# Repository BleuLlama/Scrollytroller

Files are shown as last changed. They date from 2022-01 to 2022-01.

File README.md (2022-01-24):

# Scrollytroller
Scrollytroller is a crank-based USB controller, initially inteneded for use with Playdate's Pulp web-based game development tool.

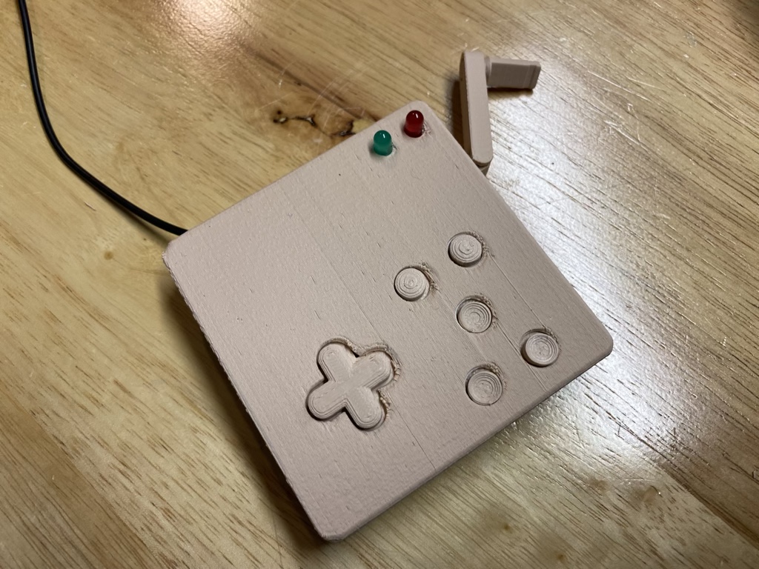
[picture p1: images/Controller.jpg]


This is a USB controller that lets you try out your Playdate Pulp games with a more accurate 
user interface, compared with using your keyboard.

# Function
The controller generates keyboard presses and mouse scroll wheel events so that the 
Pulp web player will interact with it properly.  (I added more buttons and the LEDs because I 
had the space and thought they might be useful.)

The current mouse+keyboard configuration is:

- Crank generates mouse scroll wheel events
- D-Pad generates keyboard arrow key press events
- A and B buttons - generate keyboard 'a' and 's' events
- C button (in the middle) - not used 
- D and E bottom buttons - generate 'cmd'-'s' to save and 'cmd'-'b' to toggle between the player and the editor

In general use, just the green LED will be lit.
You can switch it into "joystick" mode by pushing in the crank button.  The red LED will light up.
While in this config mode, you can turn the crank to reset it, to match the web player.
You can also press the A and B buttons to switch output modes.  The green LED should be off after
you first power up the unit.  This indicates that you're in keyboard+mouse mode.  Press the B button
to switch to Joystick mode.  The green LED will be lit.

The current joystick configuration is:

- D-Pad generates output on axis 0 (x) and axis 1 (y)
 - Range sent is from -1 to +1, with 0 being the "middle"
- A,B,D,E buttons will generate presses on buttons 0,1,2,3 respectively
 - These send 0 when idle, 1, when pressed
- Crank will output on axis 2, and the range of the axis corresponds to one full revolution of the crank.
 - This sends a value from 0..360, and loops around when a full revolution occurs in either direction

Note: The code defines the full revolution based on a couple factors that are specific to the rotary encoder that I'm using.  Mine has 20 detents per full revolution, and each detent sends a cycle of all 4 gray-code encoder phases.

# Arduino Code

The code is written with the Arduino tools, and requires the Encoder library from PJRC, and the
joystick library from Matthew Heironimus. The urls for these libraries can be found in the source
code, and may be able to be installed through the Arduino Library manager.

This project requires an Arduino board with an ATmega 32u4 chip - Leonardo, Pro Micro, or in
my case, I used the "SS Micro" clone board because I like the formfactor.

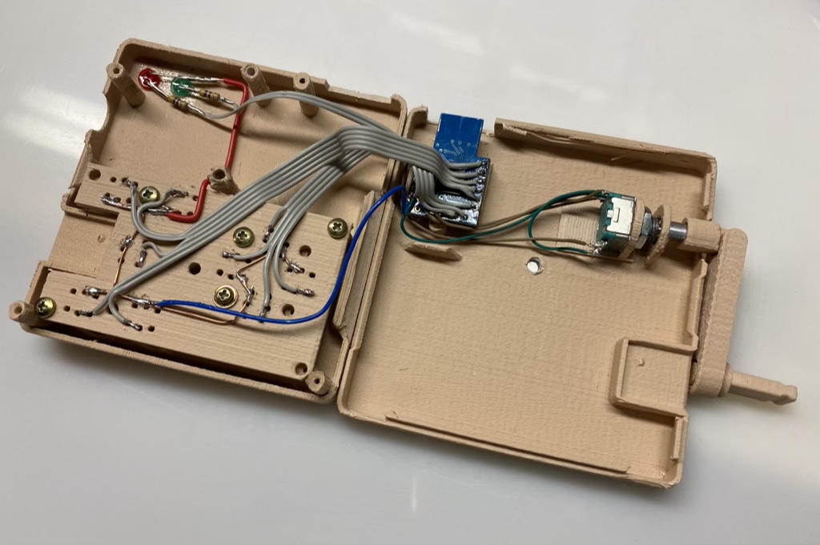
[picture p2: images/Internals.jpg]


The connection details are in the Arduino source code.  But the short of it is that 
all button io is configured using the 32u4's internal pullups, so none are needed
in the external wiring.  All connections go directly to the buttons.  The "other pin" 
on the buttons go to a common ground.  LEDs are wired up in a "source" configuration
where a HIGH from the Arduino will turn the LEDs on.  I used a 510 ohm resistor on each
to keep the current (and brightness) down quite a bit.

# Printable Model

The 3D model started out as the Adafruit "[USB Crank Controller](https://www.thingiverse.com/thing:3685130)" model on Thingiverse.  I widened
it, and created the D-Pad and buttons, as well as mounting standoffs so that it can
be screwed together.  

My version, seen above, started with that model, but I took it in [Tinkercad](https://tinkercad.com), chopped it up, and made a squareish version, with space for a D-Pad and buttons

# Links
- [Playdate](https://play.date)
- [Playdate Pulp](https://play.date/pulp)
- [Scrollytroller on Thingiverse](https://www.thingiverse.com/thing:5215011)
- [Adafruit's USB Crank Controller](https://www.thingiverse.com/thing:3685130)

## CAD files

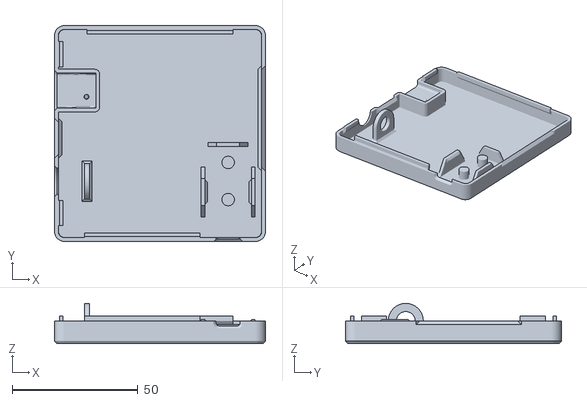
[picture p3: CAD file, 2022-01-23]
Printables/Controller/rotary usb controller - Enclosure Bottom.stl
84.0 x 86.0 x 16.0

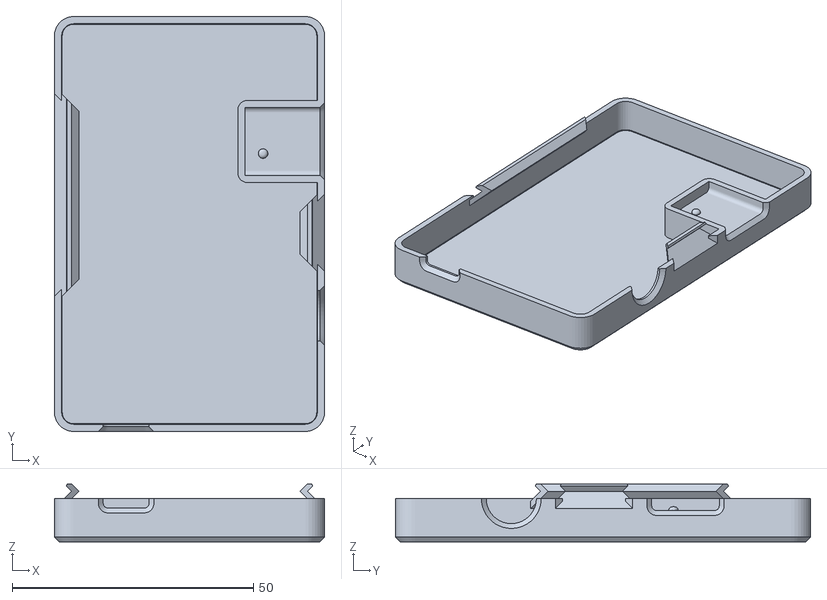
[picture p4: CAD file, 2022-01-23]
Printables/crankbox - original/crankbox-top.stl
56.0 x 86.0 x 12.0

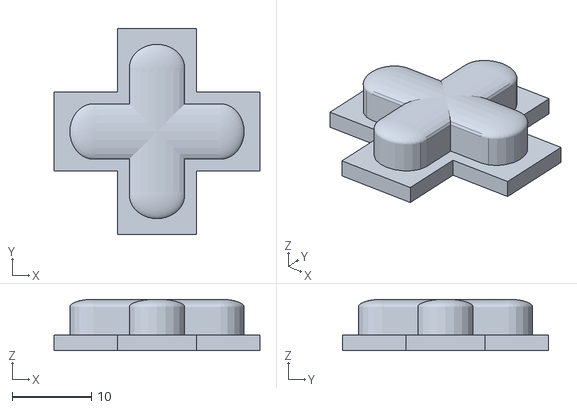
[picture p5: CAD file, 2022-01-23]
Printables/Controller/rotary usb controller - D-Pad.stl
26.0 x 26.0 x 6.50

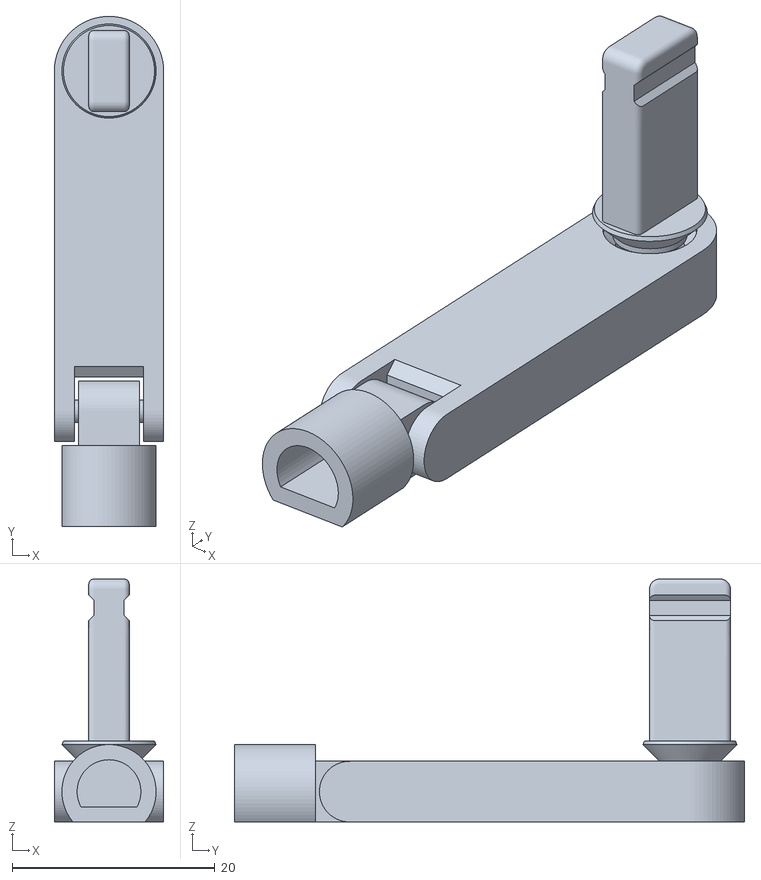
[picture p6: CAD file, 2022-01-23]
Printables/crankbox - original/hinged-crank-dual.stl
10.8 x 50.4 x 24.0

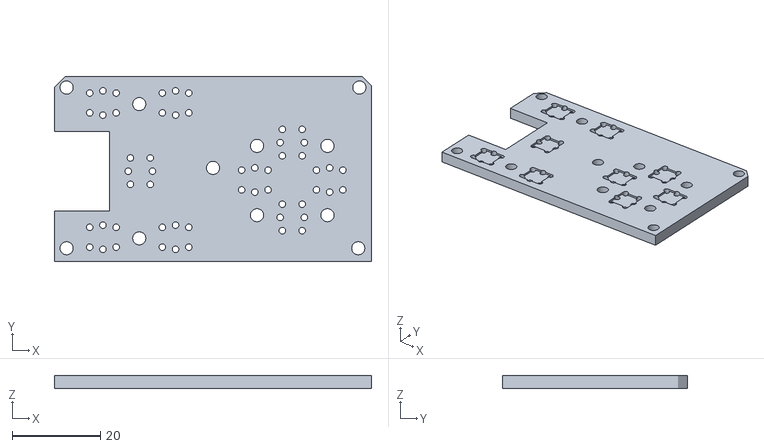
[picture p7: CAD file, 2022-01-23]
Printables/Controller/rotary usb controller - Board-6mm switches.stl
72.0 x 42.0 x 3.00

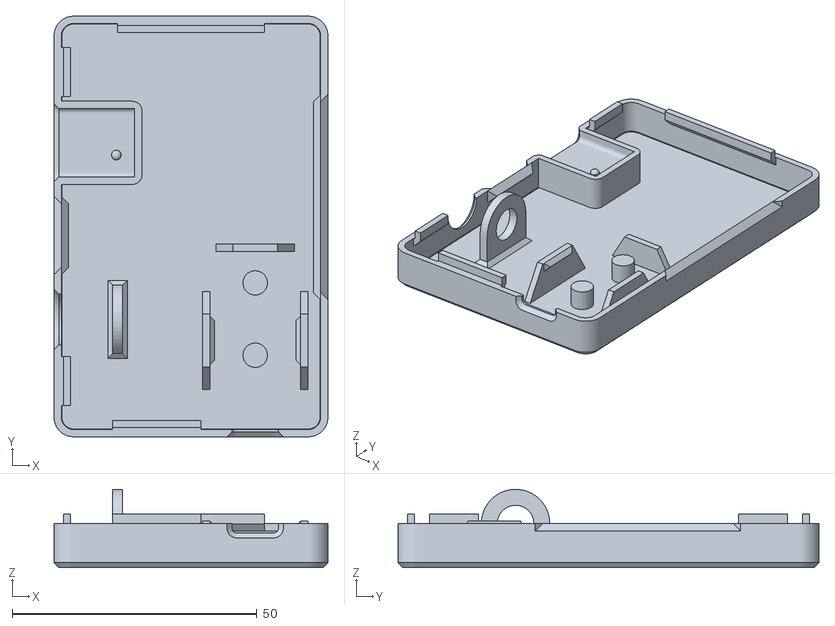
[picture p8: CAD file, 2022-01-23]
Printables/crankbox - original/crankbox-bottom.stl
56.0 x 86.0 x 16.0

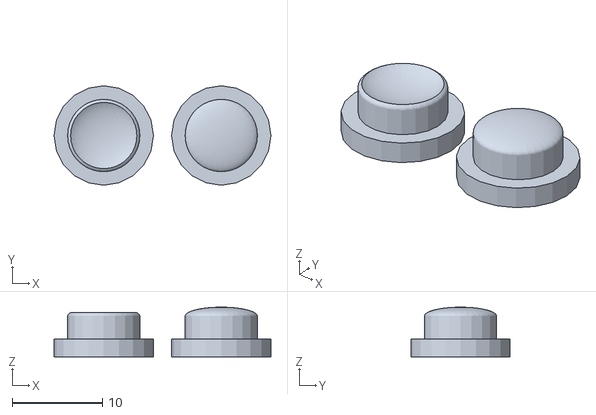
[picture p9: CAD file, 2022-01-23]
Printables/Controller/rotary usb controller - Buttons - 2mm base.stl
24.0 x 11.0 x 5.50

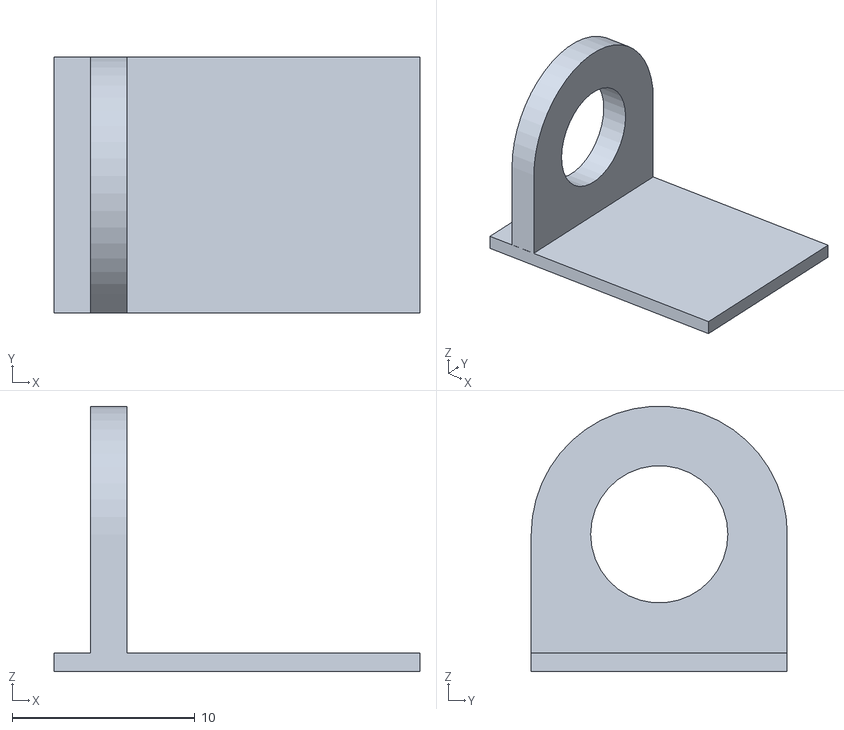
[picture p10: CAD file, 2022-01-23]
Printables/Controller/rotary usb controller - Extra Rotary Mount.stl
20.0 x 14.0 x 14.5

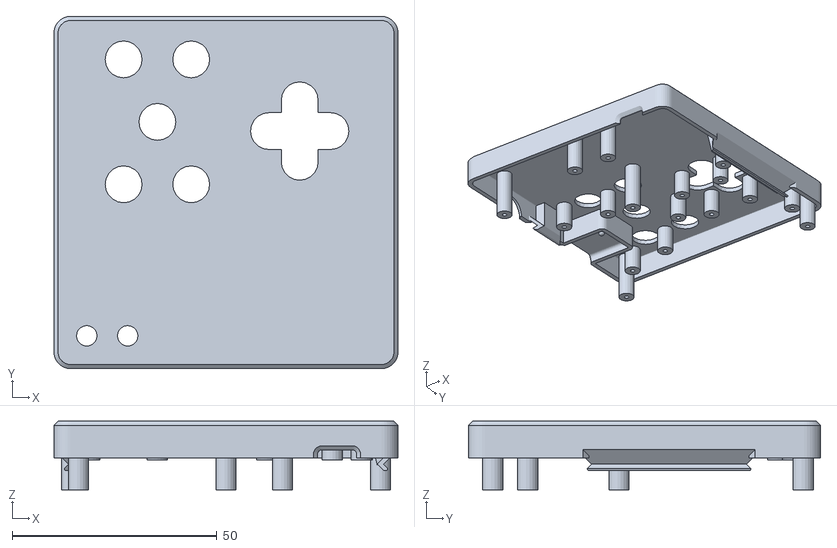
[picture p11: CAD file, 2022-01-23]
Printables/Controller/rotary usb controller - Enclosure Top - standoffs.stl
84.0 x 86.0 x 16.8

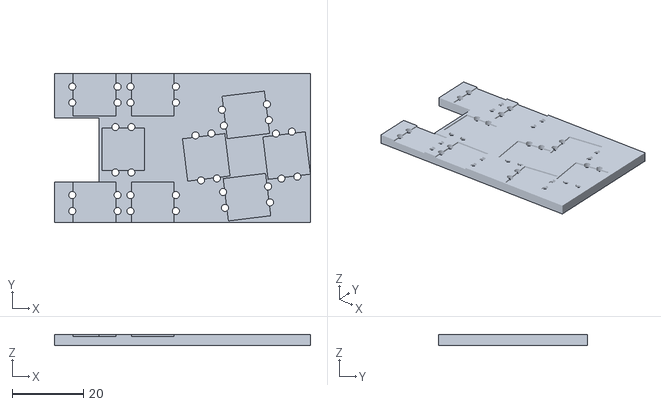
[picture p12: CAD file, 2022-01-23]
Printables/Controller/rotary usb controller - Board-12mm switches.stl
72.0 x 42.0 x 3.00

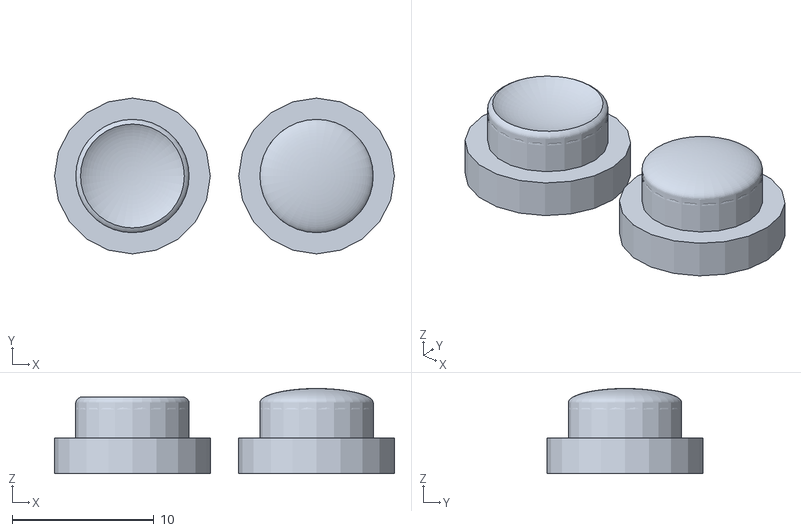
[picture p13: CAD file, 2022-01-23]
Printables/Controller/rotary usb controller - Buttons - 2.5mm base.stl
24.0 x 11.0 x 6.00

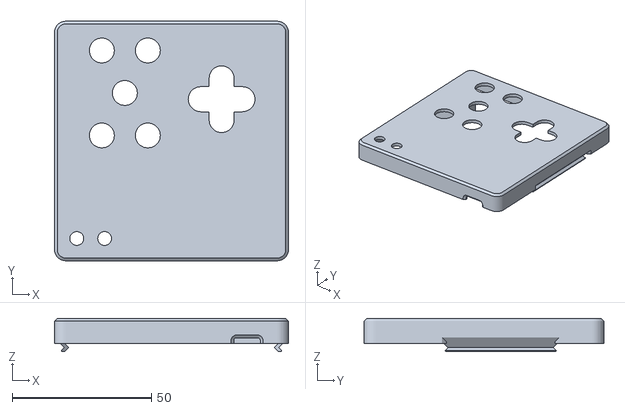
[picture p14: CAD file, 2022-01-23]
Printables/Controller/rotary usb controller - Enclosure Top - plain.stl
84.0 x 86.0 x 12.0

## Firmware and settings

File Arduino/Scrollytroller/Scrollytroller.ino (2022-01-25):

/*
 * Scrollytroller
 *    Scott Lawrence yorgle@gmail.com
 * 
 * Scroll controler, made specifically for working as a controller for the PlayDate Pulp simulator
 * 
 * crank handle sends mouse scroll events
 * buttons will send key presses
 */

/* 
  v1.02 - 2022-01-24 - Added second keypress with 3s delay (for cmd-b, f)
  v1.01 - 2022-01-23 - Two modes - Joystick, KB+Mouse
  v1.00 - 2022-01-22 - Initial version - KB+Mouse
 */

////////////////////////////////////////////////

#include <Keyboard.h> // for keyboard output
#include <Mouse.h>    // for scroll wheel
#include <Encoder.h>  // this library https://www.pjrc.com/teensy/td_libs_Encoder.html
#include <Joystick.h> // https://github.com/MHeironimus/ArduinoJoystickLibrary


#include "LLButton.h" // my classes for handling button press and keyboard sending

////////////////////////////////////////////////
// pin config 

/*
   Controller Layout:

                (GRN) (RED)

        UP         B   A     (CRANK)
    LEFT  RIGHT      C
       DOWN        E   D

  keyboard+mouse mode mapping:
   CRANK - Mouse Scroll wheel
   UP/DOWN/LEFT/RIGHT - keyboard cursor keys
   A - keyboard 's' key
   B - keyboard 'a' key
   C - (not used)
   D - Command-S (save)
   E - Command-B (toggle between Player and Editor)
   
  joystick mode mapping:
   D-Pad - x, y axes (axis 0, axis 1)
   Crank - z axis (0..360)
   A - Button 0
   B - Button 1
   C - Button 2
   D - Button 3
   
   GRN - green LED
   RED - red LED

   press the crank button and then A to switch to keyboard mode, or B to joystick mode

   
   SS Micro / Arduino Leonardo-clone (32u4) pinout
 
  rBT  D16                          A2   B-B
  GRN  D15                          A1   B-A
  RED  D14                          A0   RT
       RST                          D9   B-D
       5v                           D10  B-E
       GND                          D11  LT
           3V3  D3  D2  D1  D0  D6
                rB  rA  UP  B-C DN

 Note: on my device, D0 seems to be faulty. I could not use it for "Right dpad input" so i swapped it 
       with button C, the center button on my controller.
 */

// rotary encoder controller
#define kRotaryA (2)
#define kRotaryB (3)
#define kRotaryButton (16)

// D-Pad
#define kPadUp (1)
#define kPadDown (6)
#define kPadLeft (11)
#define kPadRight (A0)

// Buttons
#define kButtonA  (A1)
#define kButtonB  (A2)
//#define kButtonC  (0) // skipped
#define kButtonD  (9)
#define kButtonE  (10)

#define kControlCount (8) // 4 dpad. 4 buttons

// LEDs
#define kLED_Red (14)
#define kLED_Green (15)

// settings
#undef kInvertEncoder

#define kTicksPerRevolution   (20 * 4)

int outputModeJoystick = 0;
int outputInhibit = 0;


////////////////////////////////////////////////
// objects

/// setup the encoder 
#ifdef kInvertEncoder
Encoder myEnc(kRotaryB, kRotaryA);
#else
Encoder myEnc(kRotaryA, kRotaryB);
#endif


/// init button objects
LLButton rotButton( kRotaryButton );
LLButtonKeyboard *controls[ kControlCount ];

LLButtonJoystick * jcontrols[ 4 ];
LLButtonJoyButton * jbcontrols[ 4 ];


// joystick 
Joystick_ Joystick(
    JOYSTICK_DEFAULT_REPORT_ID,
    JOYSTICK_TYPE_JOYSTICK, //JOYSTICK_TYPE_MULTI_AXIS,
  4, 0,                  // Button Count, Hat Switch Count
  true, true, true,     // X and Y, and Z Axis
  false, false, false,    //  Rx, Ry, or Rz
  false, false,           // rudder or throttle
  false, false, false);   // accelerator, brake, or steering


////////////////////////////////////////////////
// Arduino core functions

// setup
//  standard setup() call.  get everything going!
void setup() {
  /*
  Serial.begin( 115200 );
  while( !Serial );
  Serial.println( "Ready." );
  */
  
  Mouse.begin();
  Keyboard.begin();

  setup_Joystick();
 
  setup_Buttons();
  setup_LEDs();

}

// loop
//  poll all of our inputs, generating appropriate events and stuff
void loop() {
  poll_Encoder();
  if( !outputInhibit ) {
    poll_Buttons();
  }
}

////////////////////////////////////////////////
// Joystick
void setup_Joystick()
{
  Joystick.begin();
  Joystick.setXAxisRange(-1, 1);
  Joystick.setYAxisRange(-1, 1);
  Joystick.setZAxisRange(0, 360);

  Joystick.setButton(0, 0); // A 
  Joystick.setButton(1, 0); // B
  Joystick.setButton(2, 0); // D
  Joystick.setButton(3, 0); // E
}

////////////////////////////////////////////////
// Buttons

//  setup_Buttons
//    Initialize all of our "controls" class instatiation thingies
void setup_Buttons()
{  
  // these map to the Pulp player controller
  // joystick controls
  jcontrols[0] = new LLButtonJoystick( kPadUp, 0, 1 );
  jcontrols[1] = new LLButtonJoystick( kPadDown, 0, -1 );
  jcontrols[2] = new LLButtonJoystick( kPadLeft, -1, 0 );
  jcontrols[3] = new LLButtonJoystick( kPadRight, 1, 0 );
  
  jbcontrols[0] = new LLButtonJoyButton( kButtonA, 0 );
  jbcontrols[1] = new LLButtonJoyButton( kButtonB, 1 );
  jbcontrols[2] = new LLButtonJoyButton( kButtonD, 2 );
  jbcontrols[3] = new LLButtonJoyButton( kButtonE, 3 );

  // kyb/mouse controls
  controls[0] = new LLButtonKeyboard( kPadUp, KEY_UP_ARROW );
  controls[1] = new LLButtonKeyboard( kPadDown, KEY_DOWN_ARROW );
  controls[2] = new LLButtonKeyboard( kPadLeft, KEY_LEFT_ARROW );
  controls[3] = new LLButtonKeyboard( kPadRight, KEY_RIGHT_ARROW );
  controls[4] = new LLButtonKeyboard( kButtonA, 's' );
  controls[5] = new LLButtonKeyboard( kButtonB, 'a' );

  controls[6] = new LLButtonKeyboard( kButtonD, 's', KEY_LEFT_GUI ); // save
  controls[7] = new LLButtonKeyboard( kButtonE, 'b', KEY_LEFT_GUI, 'f' ); // toggle between player and editor
}

//  poll_Buttons
//    poll each button to generate appropriate events.
//
void poll_Buttons()
{
  if( outputModeJoystick ) {
    for( int j = 0 ; j < 4 ; j++ ) {
      jcontrols[ j ]->Poll();
      jbcontrols[ j ]->Poll();
    }
  } else { 
    for( int i = 0 ; i < kControlCount ; i++ ) {
      controls[i]->Poll();
    }
  }
}


////////////////////////////////////////////////
// LEDs 

//  setup_LEDs
//    Setup pins for the LEDs and get them in a known state
void setup_LEDs()
{
  pinMode( kLED_Red, OUTPUT );
  pinMode( kLED_Green, OUTPUT );

  // flash them on, at poweron just to indicate they both work
  digitalWrite( kLED_Red, HIGH);
  digitalWrite( kLED_Green, HIGH );
  delay( 200 );
  digitalWrite( kLED_Red, LOW );
  digitalWrite( kLED_Green, LOW );
  // and start with them in a known off state

  // now indicate "ready"
  LED_Ready();
}


// LED_Ready
//  Indicate the "ready" state
void LED_Ready()
{
  // ready: red off, green on
  digitalWrite( kLED_Red, LOW );
  digitalWrite( kLED_Green, HIGH );
}


// LED_Ready
//  Indicate an "error" or "busy" state
void LED_Error()
{
  // error: red on, green off
  digitalWrite( kLED_Red, HIGH );
  digitalWrite( kLED_Green, LOW );
}


////////////////////////////////////////////////
// Rotary Encoder

// poll_Encoder
//  read the encoder and send mouse scroll events
void poll_Encoder()
{
  // states from call-to-call
  static long oldPosition = -999;
  long newPosition = 0;

  // for now, press the encoder button to "hold" rotational reporting, 
  // so that we can line up the arm with the simulator's arm.
  int bEvent = rotButton.Poll();
  switch( bEvent ) {
    case kEventPressed:
      LED_Error(); // indicate that something is different.
      outputInhibit = 1;
      
      // setup the LEDs for showing mode
      // red indicates we're inhibiting output
      digitalWrite( kLED_Red, HIGH );
      // green indicates keyboard or joystick
      digitalWrite( kLED_Green, outputModeJoystick );
      break;
      
    case kEventPressing:
      // eat rotation deltas
      myEnc.write( 0 );
      oldPosition = 0;
      outputInhibit = 1;
      // check for Button A/B press during this time
      
      if( controls[4]->Poll() == kEventPressed ) { // B button
        outputModeJoystick = 0;
      }
      if( controls[5]->Poll() == kEventPressed ) { // A button
        outputModeJoystick = 1;
      }
      digitalWrite( kLED_Green, outputModeJoystick );
      
      break;
      
    case kEventReleased:
      outputInhibit = 0;
      LED_Ready(); // back to normal!
      break;
      
    default: // or idle
      // user isn't pressing, send them events through!
      outputInhibit = 0;
      
      // checks for the encoder itself
      newPosition = myEnc.read();

      if( outputModeJoystick ) {
        if( newPosition < 0 ) {
          newPosition += kTicksPerRevolution;
          
          myEnc.write( newPosition );
        }
        
        Joystick.setZAxis( ( newPosition % kTicksPerRevolution ) * 360.0 / kTicksPerRevolution );
        
      } else {
          
        // since each "click" of the encoder goes through all four complete phases on our 
        // encoder... 00 -> 01 -> 11 -> 10 -> 00  (or the other way around), we want to only
        // respond for each "click" so divide the pulses by 4.
        
        if (newPosition/4 != oldPosition/4) {
          oldPosition = newPosition;
          Mouse.move( 0, 0, newPosition/4 );
          myEnc.write( 0 ); // reset it so we're doing a delta
        }   
      }
      break;
  }
}

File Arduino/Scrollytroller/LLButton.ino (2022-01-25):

/*  LLButton
 *   2022-01-22 - Scott Lawrence - yorgle@gmail.com
 *   
 *   Classes to encapsulate gpio -> button events and gpio -> keypesses
 */



#include "LLButton.h"

////////////////////////////////////////////////
// LLButton
//
//  a class to encapsulate the actions of a button attached to an arduino pin
//  buttons in this implementation are configured as INPUT_PULLUP, and thus
//  require no external pullups or pulldowns.  Buttons should short the data pin
//  to ground when a "press" occurs

// constructor
//   pass in the gpio pin specifier ie 8, 9, A3, etc
LLButton::LLButton( int ppin )
  : prev( HIGH )
  , curr( HIGH )
  , pin( ppin )
  , event( kEventIdle )
{
  // initialize the GPIO
  pinMode( this->pin, INPUT_PULLUP );
}


// LastEvent
//  just return the last event that Poll() returned
int LLButton::LastEvent()
{
  return this->event;
}


// Poll
//  called to check the states of the buttons, set the event state
int LLButton::Poll()
{
  int raw = digitalRead( this->pin );
  if( raw != prev ) {
    // state changed!
    if( prev == HIGH ) {
      this->event = kEventPressed;
    } else {
      this->event = kEventReleased;
    }
    prev = raw;
  } else {
    // no change
    if( raw == HIGH ) {
      this->event = kEventIdle;
    } else {
      this->event = kEventPressing;
    }
  }
  return this->event;
}


////////////////////////////////////////////////
// LLButtonKeyboard
//
//  This is a subclass of the above. It adds in keyboard functionality
//  that is, when the gpio pin is "pressed" it will send a keyboard key-down event,
//  with the specified key.  (and wrapped in the modifier if appropriate)

// constructor with the key passed in (no modifier)
LLButtonKeyboard::LLButtonKeyboard( int pin, int pkey )
  : LLButton( pin )
  , key( pkey )
  , key2( 0 )
  , modifier( -1 ) // indicate "no modifier"
{
}

// constructor with the key and modifier passed in
LLButtonKeyboard::LLButtonKeyboard( int pin, int pkey, int pmodifier )
  : LLButton( pin )
  , key( pkey )
  , key2( 0 )
  , modifier( pmodifier )
{
}

// constructor with the key and modifier passed in
LLButtonKeyboard::LLButtonKeyboard( int pin, int pkey, int pmodifier, int pkey2 )
  : LLButton( pin )
  , key( pkey )
  , key2( pkey2 )
  , modifier( pmodifier )
{
}

// Poll
//  // poll the button pin and generate key presses where appropriate
int LLButtonKeyboard::Poll()
{
  int evt = LLButton::Poll();

  if( evt == kEventPressed ) {
    if( this->modifier > 0) Keyboard.press( this->modifier );
    Keyboard.press( this->key );
  }
  if( evt == kEventReleased ) {
    if( this->modifier > 0 ) Keyboard.release( this->modifier );
    Keyboard.release( this->key ); 

    if( this->key2 != 0 ) {
      delay( 3000 );
      Keyboard.press( this->key2 );
      delay( 250 );
      Keyboard.release( this->key2 );
    }
  }
  
  return evt;
}



////////////////////////////////////////////////
// LLButtonJoystick
// 
//  Subclass of the above, generates X/Y axis joystick controller events

// constructor with the key passed in (no modifier)
LLButtonJoystick::LLButtonJoystick( int pin, int xMul, int yMul  )
  : LLButton( pin )
  , xMultiplier( xMul )
  , yMultiplier( yMul )
{
}

int LLButtonJoystick::Poll()
{
  int evt = LLButton::Poll();

  if( evt == kEventPressed ) {
    // set the value on the appropriate axis
    if( this->xMultiplier != 0 ) {
      Joystick.setXAxis( this->xMultiplier );
    } else {
      Joystick.setYAxis( this->yMultiplier );
    }
    
  }
  if( evt == kEventReleased ) {
    // center the appropriate axis
    if( this->xMultiplier != 0 ) {
      Joystick.setXAxis( 0 );
    } else {
      Joystick.setYAxis( 0 );
    }
    
  }
  
  return evt;
}


////////////////////////////////////////////////
// LLButtonJoyButton
// 
//  Subclass of the above, generates joystick controller button events


LLButtonJoyButton::LLButtonJoyButton( int pin, int _joybutton )
: LLButton( pin )
  , joybutton( _joybutton )
{
}

int LLButtonJoyButton::Poll()
{
  int evt = LLButton::Poll();
  
  if( evt == kEventPressed ) {
    // set the value on the appropriate axis
    Joystick.setButton( this->joybutton, 1 );
  }
  if( evt == kEventReleased ) {
    Joystick.setButton( this->joybutton, 0 );
  }

  return evt;
}
